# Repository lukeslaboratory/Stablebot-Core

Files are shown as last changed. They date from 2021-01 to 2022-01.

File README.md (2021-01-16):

# Stablebot-Core
High-Performance CoreXY printer capable of Toolchanging and Ease-of-fabrication



The goal is to make an any-size machine that's capable of high-speed printing as well as toolchanging. 

This is the first attempt at release - Some files may be not correct. Feel free to shoot me an issue. This export is of my Currently built large machine (622x622x1000) with some new improvements made for my small machine. 

[Extrusion Sizer](https://docs.google.com/spreadsheets/d/1divmRL_RmXVi3Z5ql3C13kvea18Q-DxR8h9kwekK1nM/)

Review additional design discussion on [my blog](https://www.lukeslab.online/blog/tag/Stablebot)

Todo:
1) Assembly Instructions
2) Complete BOM (seriously, just buy a bunch of m3 and m5 screws)
3) Release Tools, for both Single and Multi Use
  a) Jubilee TC Head
4) TAMV Unit (pending Kickstarter)
5) Better LCD handling
6) Dedicated Electronics Box
7) Wire management for TC units - Single-tool will use improved wiring using cable chains - In development, will be used on single-tool units, and used for cabling to E3D Stepper Head

Any Questions, Create issues or hit me up on discord - https://discord.gg/daXRDZf or twitter - [@LukesLaboratory](https://twitter.com/LukesLaboratory)
You can also catch me on the [Jubilee discord](https://discord.gg/bPFuWEHP) - an incredible amount of learning was done here. 

Liscense

Project is liscensed under https://creativecommons.org/licenses/by-nc/3.0/

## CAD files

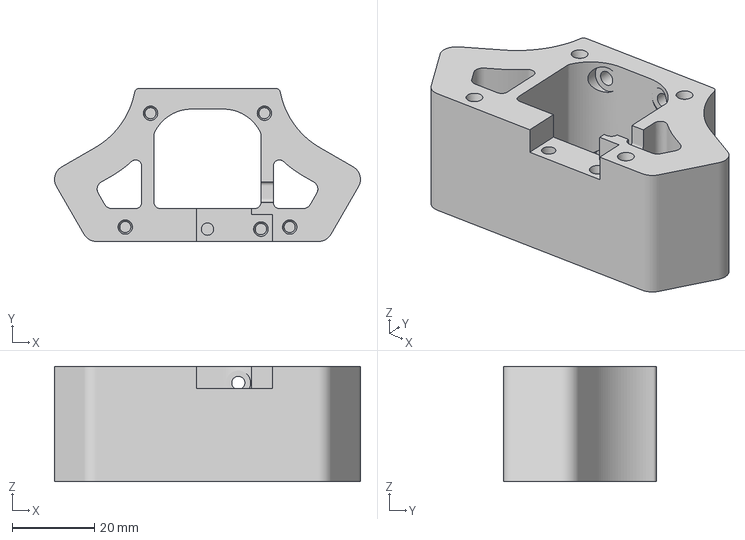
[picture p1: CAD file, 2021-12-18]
STL's/Carriage - REL_toolchanger_carriage_assembly v18_Body4.3mf
74.4 x 37.2 x 28.0 mm

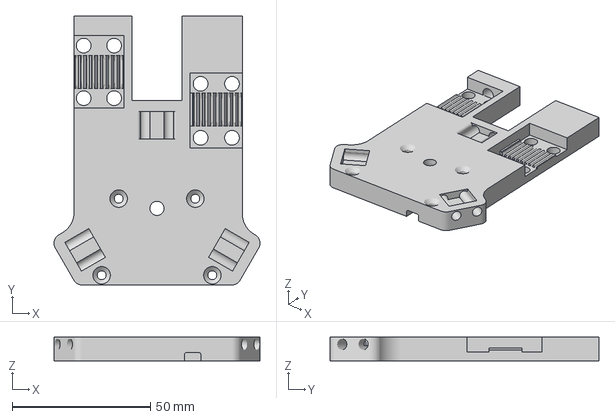
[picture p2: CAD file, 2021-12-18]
STL's/Carriage - REL_toolchanger_carriage_assembly v18_Body2.3mf
74.4 x 97.2 x 8.60 mm

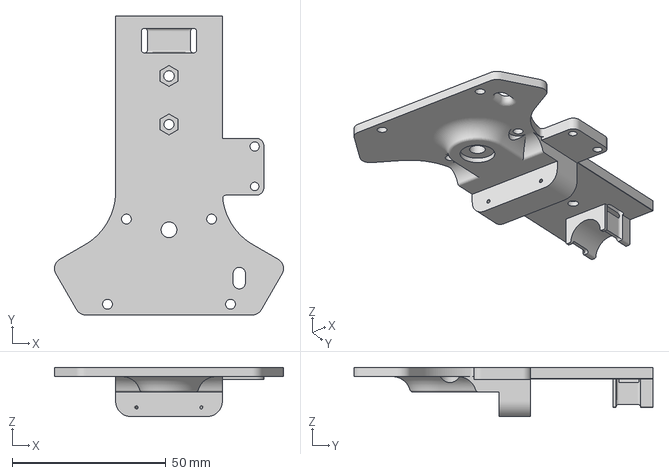
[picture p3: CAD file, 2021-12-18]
STL's/Carriage - REL_toolchanger_carriage_assembly v18_Body1.3mf
74.4 x 97.2 x 16.0 mm

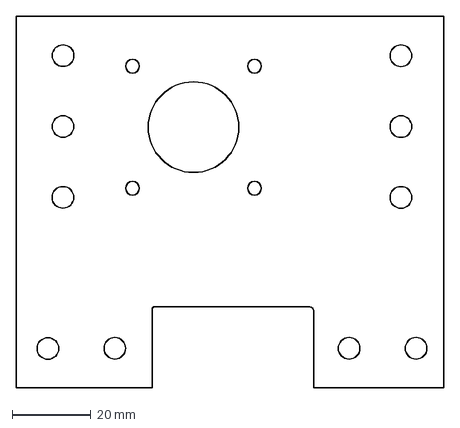
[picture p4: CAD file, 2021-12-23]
DXF's (laser cut)/Rear_Z_Motor_Plate.dxf
108.5 x 94.3 mm

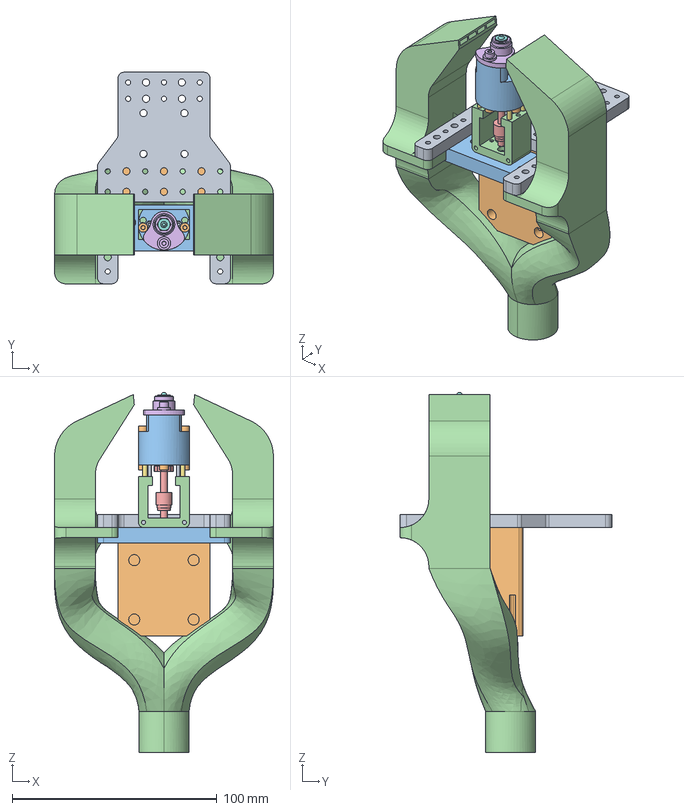
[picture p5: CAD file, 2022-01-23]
Step/New_Gantry.step
107.1 x 103.5 x 176.0 mm
Metal_Bracket
Metal Bracket Support
LOW-FI hot block magnum+_MAGNUM+ 1.75
LOW-FI heat sink magnum+_Magnum+, Prime
LOW-FI heat break 1.75
LOW-FI nozzle insulator
LOW-FI tubes_standoff x 4
LOW-FI nozzle_0.8 VANADIUM
LOW-FI M1.6-16 socket head cap screw x 2
LOW-FI M2.5-4 socket head cap screw x 5
Hotend Mount
CPAP Mag+Metalmount

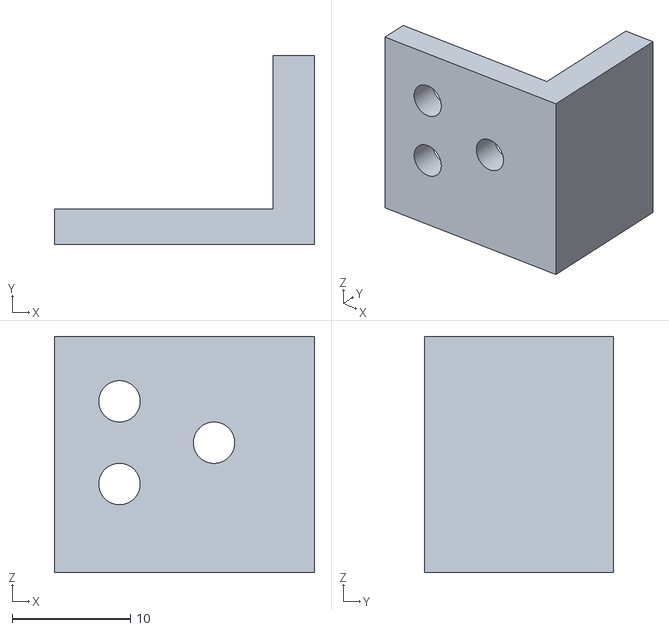
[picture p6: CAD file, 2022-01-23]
STL's/X-Stopper.stl
22.0 x 16.0 x 20.0

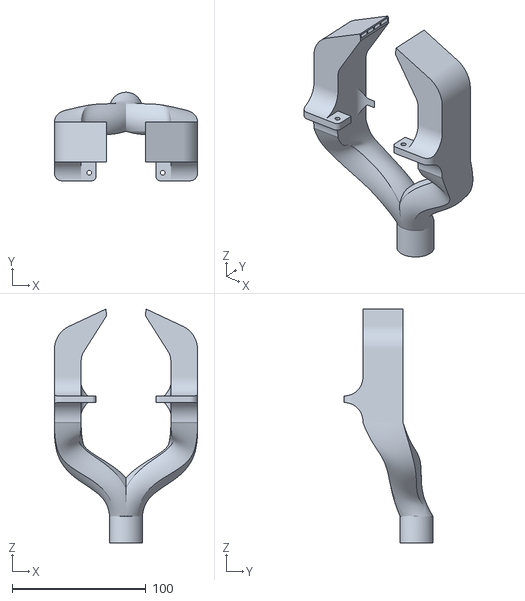
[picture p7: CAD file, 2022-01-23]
STL's/CPAP Mag+Metalmount.stl
107.2 x 66.3 x 175.0

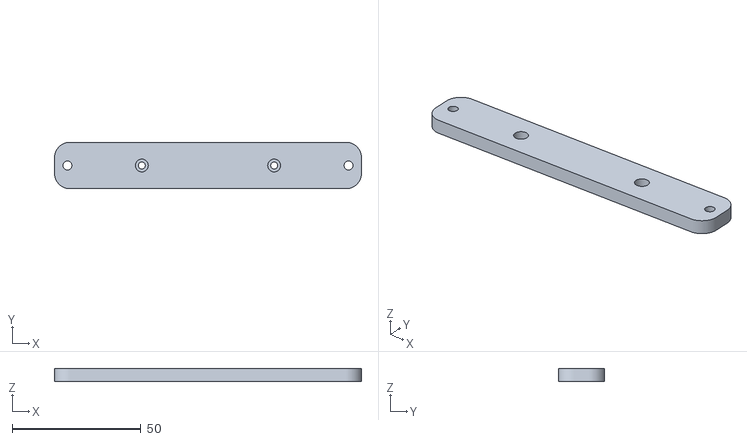
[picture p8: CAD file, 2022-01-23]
STL's/External Stepper Mount.stl
119.0 x 18.0 x 5.00

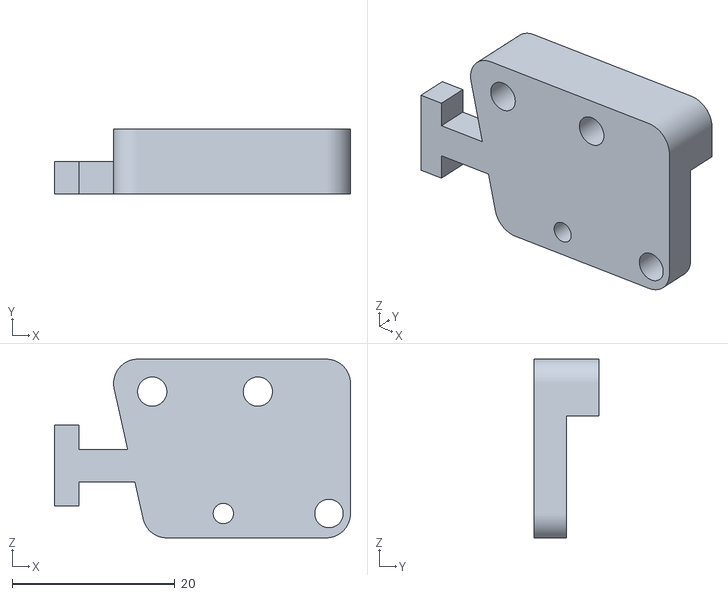
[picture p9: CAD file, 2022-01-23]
STL's/Y-Min-Bracket.stl
36.4 x 8.00 x 22.0

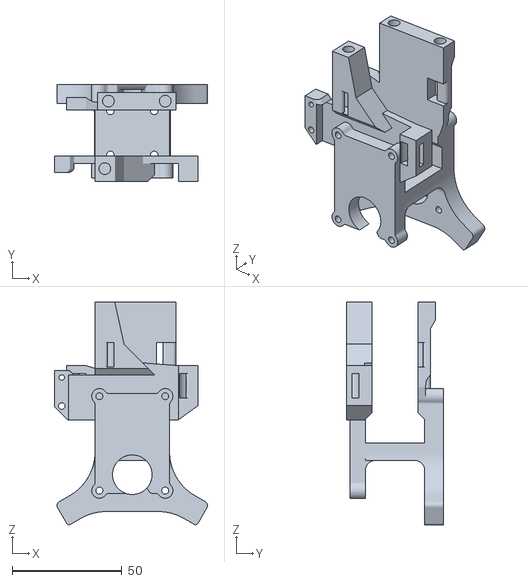
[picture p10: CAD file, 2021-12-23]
STL's/Toolchanger Plastic UnderCarriage e3d.stl
69.8 x 44.0 x 101.6

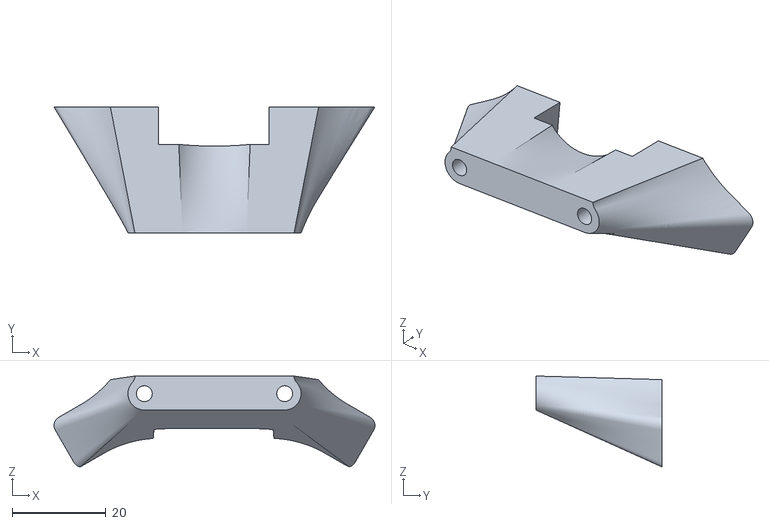
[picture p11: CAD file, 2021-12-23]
STL's/Plastic Underbrace.stl
68.6 x 27.0 x 19.5

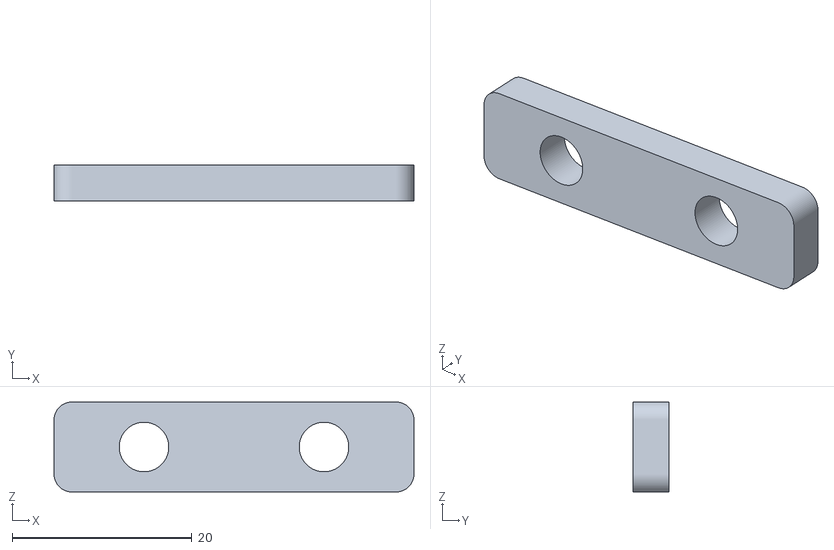
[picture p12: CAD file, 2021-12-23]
STL's/Din Spacer v1.stl
40.0 x 4.00 x 10.0

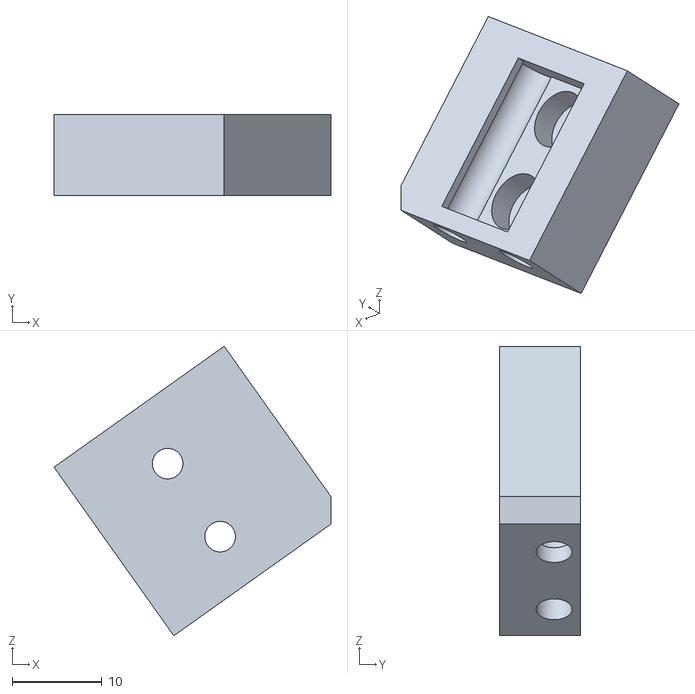
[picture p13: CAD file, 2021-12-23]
STL's/Plastic Body Maxwell Bed Mount.stl
30.8 x 9.00 x 32.2

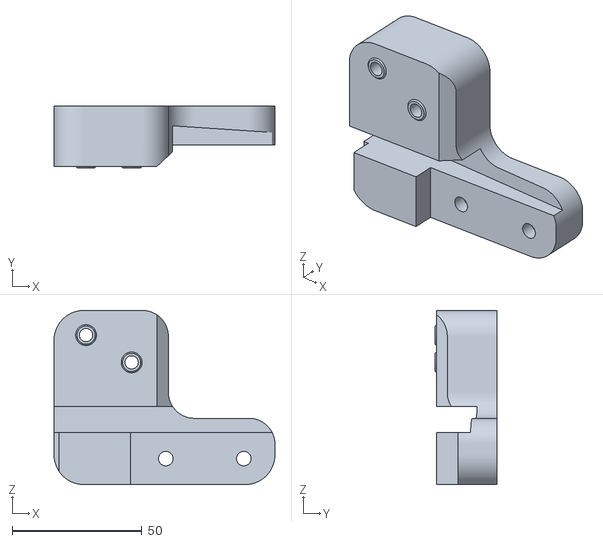
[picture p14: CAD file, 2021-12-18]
STL's/Double_Shear_Rear(Mirror).stl
85.0 x 23.7 x 67.0

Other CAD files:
STL's/X Gantry.step
STL's/Rear Z Plastic Peice.stl
STL's/Component449.3mf
STL's/ToolPostBase.3mf
STL's/17.5mm standoff.3mf
STL's/3mm Standoff.3mf
STL's/Attachment Front Z(Mirror).stl
STL's/Back Plate.3mf
STL's/Bearing Top.stl
STL's/Belt_Motor_Tensioner.stl
STL's/DoubleShear(Mirror).stl
STL's/Double_Shear_Rear.stl
STL's/Euclid Mount.3mf
STL's/FrontBelt2.3mf
STL's/Front_Belt_1.3mf
STL's/Gantry_Top_Support(Mirror).stl
STL's/Gantry_Top_Support_StableBot Core v183_Body1_.stl
STL's/Gantry_Top_Support_StableBot Core v183_Body2_.stl
STL's/Internal Cablechain Handling.stl
STL's/Orbiter_Slice_Tool Try 2_Probe_Holder_Euclid v1.3mf
STL's/Plastic Base.3mf
STL's/Plastic_Motor_Spacing(Mirror).stl
STL's/Plastic_Motor_Spacing.stl
STL's/Spacer+Standoff Plate(Mirror).stl
STL's/Spacer+Standoff Plate.stl
STL's/StableBot Core_ToolPostJub48 v2.3mf
STL's/Top Plate REL.stl
STL's/TopPlateREL.3mf
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

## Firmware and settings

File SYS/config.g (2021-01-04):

; Configuration file for Duet 3 (firmware version 3)
; executed by the firmware on start-up
;
; generated by RepRapFirmware Configuration Tool v2.1.4 on Thu Dec 26 2019 17:05:21 GMT-0600 (Central Standard Time)

; General preferences
M80
G90                                          ; send absolute coordinates...
M83                                          ; ...but relative extruder moves
M550 P"StableBot"                               ; set printer name

M667 S1                                      ; select CoreXY mode

;+++++++++++++++++++++++++++++++++++MOTION SYSTEM++++++++++++++++++++++++++++++

; Drives
M569 P0.1 S1                    ; physical drive 0.1 goes forwards XY
M569 P0.0 S0                    ; physical drive 0.0 goes forwards XY
M569 P0.2 S0                    ; physical drive 0.2 goes forwards Coupler
M569 P0.3 S1				    ; physical drive 0.3 goes backwards Z
M569 P0.4 S1				    ; physical drive 0.4 goes backwards Z
M569 P0.5 S0                    ; physical drive 0.5 goes backwards Z
M569 P1.0 S0					; Extruder 1
M569 P1.1 S0					; Extruder 2
M569 P1.2 S0					; Extruder 3
M584 X0.1 Y0.0 Z0.3:0.4:0.5 C0.2 E1.0:1.1:1.2                     ; set drive mapping
M350 X16 Y16 E16:16:16 Z16 I1                      						  ; configure microstepping with interpolation
M350 C8 E16:16:16 I0														  ; No interpolation on Z Axis
M92 X160.00 Y160.00 Z1600 E409.00:409.00:830 C100         ; set steps per mm
M566 X360 Y360 Z600 E1800:1800:1800 C2          ; set maximum instantaneous speed changes (mm/min)
M203 X20000.00 Y20000.00 Z840 E10800.00:10800:10800 C5000   ; set maximum speeds (mm/min)
M201 X2000.00 Y2000.00 Z18 E2500:2500:2500 C400      ; set accelerations (mm/s^2)
M906 X2300 Y2300 Z2000 E1600:1600:1900 C600 I60             ; set motor currents (mA) and motor idle factor in per cent
M84 S120                                      ; Set idle timeout


; Axis Limits
M208 X-17 Y-14 Z0 C0 S1                             ; set axis minima
M208 X622 Y660 Z950 C500 S0                       ; set axis maxima
M671 X290.0:-32:627 Y658:185:186 S20 ; leadscrews at rear middle, front left+right

; Endstops
M574 X1 S1 P"io2.in"                         ; configure active-low endstop for low end on X via pin io2.in
M574 Y1 S1 P"io0.in"                         ; configure active-low endstop for low end on Y via pin io0.in
;M574 Y2 S1 P"!io1.in"			      ; configure active-low endstop for high end on Y via pin io1.in


; Z-Probe

M558 P5 C"io3.in" H10 F120 T3600      ; set Z probe type to simp switch and the dive height + speeds
G31 X0 Y0 Z0 P200                        ; set Z probe trigger value, offset and trigger height
;M557 X15:600 Y15:600 S30                     ; define mesh grid - Whole Bed
M557 X10:590 Y10:590 P21:21                     ; define mesh grid - Center Small

; Bed Heater
M308 S0 P"temp3" Y"thermistor" T100000 B4138 A"Bed1" ; configure sensor 0 as thermistor on pin temp0
M950 H0 C"out1" T0                           ; create bed heater output on out0 and map it to sensor 0
M143 H0 S120                                 ; set temperature limit for heater 0 to 120C
M307 H0 R0.486 C285.0 D1.47 S0.75    ; disable bang-bang mode for the bed heater and set PWM limit
M140 H0                                      ; map heated bed to heater 0

; Lights
M950 F15 C"out9" Q500                         ; create fan 2 on pin out7 and set its frequency
M106 P15 S0 C"LEDS" H-1                               ; set fan 2 value. Thermostatic control is turned off

;+++++++++++++++++++++++++++++++++Hotends++++++++++++++++++++++++++++++++++++++++++++++
;MOVED TO MACRO BELOW - allows for scripting updates 
M98 P"/macros/tool_conf"
;+++++++++++++++++++++++++++++++++Hotends++++++++++++++++++++++++++++++++++++++++++++++

; Custom settings are not defined

;Servo				;Initial Setup for TAMV Cam
;M950 S0 C"io7.out"  ;Define pin for Servo
;M280 P0 S2350		;moves to "store" position

M98 P"/macros/TAMV/StoreCam"

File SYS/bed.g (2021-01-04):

; bed.g
; called to perform automatic bed compensation via G32
echo "you started fucking stupid bedleveling"
M561                         ; clear any existing bed transform
T-1
; If the printer hasn't been homed, home it
if !move.axes[0].homed || !move.axes[1].homed || !move.axes[2].homed
 G28
 echo "you're not home you dumbfuck!"
  
M558 H15 F480 T6000 S0.05 A1 ; Ensure that Dive Height is safe for Bed Tramming
G1 Z15
;Run initial 3 point leveling routine, X290.0:-32:627 Y658:185:186 leadscrews at rear middle, front left+right
M561 ; Clears bed leveling 
;Rear left
G1 X5 Y600 F9000
G30 P0 X5 Y600 Z-99999
;Rear Right
G1 X587 Y600 F9000
G30 P1 X587 Y600 Z-99999
;Front Left
G1 X300 Y10 F9000
G30 P2 X300 Y10 Z-99999 S3




;while true
;  if iterations = 5
;    abort "Too many auto calibration attempts"
;  if move.initialDeviation.deviation < 0.01 
;    if move.calibrationDeviation.deviation < move.initialDeviation.deviation + 0.005
;      if move.calibrationDeviation.deviation > move.initialDeviation.deviation - 0.005
;        break
;  echo "Repeating calibration because initial deviation (" ^ move.initialDeviation.deviation ^ "mm) must be < 0.01"
;  echo "and (" ^ move.calibrationDeviation.deviation ^ "mm) must be within 0.005 of initialDeviation"
;  echo "you're in the loop now you dumbfuck"


;Rear left
G1 X5 Y600 F9000
G30 P0 X5 Y600 Z-99999
;Rear Right
G1 X587 Y600 F9000
G30 P1 X587 Y600 Z-99999
;Front Left
G1 X300 Y10 F9000
G30 P2 X300 Y10 Z-99999 S3
M558 H4 F180

;echo "Auto calibration successful, deviation", move.calibrationDeviation.deviation ^ "mm"
;echo "Auto calibration successful, initialDeviation", move.initialDeviation.deviation ^ "mm"  
:G29
G1 X300 Y300
G30

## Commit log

2021-01-04 Upload Configs and Simple Macros
    Initial Commit - These Macros are Kludged together based on My machine and how I currently use them. They are not a finished state, but all are functional.
    [Purge.g, Wipe.g, bed.g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]
2021-12-18 Updated parts for V1 Release
    Deleted all old files and updated for upcoming V1 Release
    [17.5mm standoff.3mf, 3mm Standoff.3mf, Attachment Front Z(Mirror).stl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]
2021-12-23 Swapping Parts for V1 Release
    New parts uploaded
    [Belt_Transfer.dxf, Din Spacer v1.stl, Funky_Joint_Rear.dxf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]
2021-12-23 Adding e3d TC parts
    [Plastic Underbrace.stl, Toolchanger Plastic UnderCarriage e3d.stl]
2022-01-23 Update with some additional components
    Uploading new files
    [CPAP Mag+Metalmount.stl, External Stepper Mount.stl, New_Gantry.step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]
2022-01-23 Create X Gantry.step
    [X Gantry.step]
